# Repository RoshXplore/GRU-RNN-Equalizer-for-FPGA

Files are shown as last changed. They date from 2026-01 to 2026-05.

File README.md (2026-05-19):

# GRU(RNN)-Based Neural Network Optical Channel Equaliser on FPGA

> Note:
> This repository includes the project architecture, verification flow, FPGA deployment results, and supporting implementation files. Some internal RTL modules related to ongoing development and research work are intentionally omitted from the current public release.

Implementation of a GRU (Gated Recurrent Unit) based neural network equalizer in Verilog for digital communication systems, including both inference and on-chip training using Backpropagation Through Time (BPTT).

This project explores how recurrent neural networks can be implemented directly in hardware for adaptive channel equalization, where the communication channel characteristics vary over time and traditional DSP equalizers become less effective.

The work includes:

* Python/PyTorch model development
* Verilog RTL implementation
* FPGA deployment on Intel DE10-Lite
* On-chip GRU training using BPTT
* Gradient descent based weight updates
* RTL and FPGA verification

---

# Project Motivation

Communication channels introduce:

* noise,
* distortion,
* and inter-symbol interference (ISI).

Traditional equalizers work well for linear systems, but their complexity increases significantly for non-linear and time-varying channels.

Recurrent Neural Networks (RNNs), especially GRUs, are better suited for this problem because they maintain a hidden state that acts as memory across time steps. This allows the network to learn temporal dependencies caused by ISI.

The objective of this project was to design a trainable GRU architecture completely in Verilog that could:

* perform sequence-based equalization,
* execute inference directly on FPGA,
* and update weights on-chip using BPTT and SGD.

---

# Why GRU Instead of Standard RNN?

Standard RNNs suffer from:

* vanishing gradients,
* exploding gradients,
* unstable long-sequence training.

GRUs solve this using gating mechanisms:

* Reset Gate
* Update Gate

These gates regulate:

* how much past information should be forgotten,
* and how much should be retained.

This improves training stability and allows the model to learn temporal channel behavior more effectively.

---

# Project Evolution

The project evolved through two major stages.

---

# Phase 1 — BPSK GRU Equalizer

The first version focused on:

* understanding GRU inference in hardware,
* FPGA deployment,
* and validating basic equalization capability.

## Features

* BPSK modulation support
* GRU inference engine in Verilog
* Fixed-point arithmetic
* FPGA deployment on Intel DE10-Lite
* Python-trained weights exported into hardware

## Results

* Successfully deployed on FPGA
* Less than 1% prediction error
* Correct symbol prediction across all test cases

---

# Phase 2 — QPSK + On-Chip Training

The second version significantly expanded the architecture.

Major improvements included:

* QPSK support
* IEEE-754 floating-point arithmetic
* Serialized hardware architecture
* Backpropagation Through Time (BPTT)
* On-chip gradient calculation
* On-chip SGD weight updates
* Gradient clipping
* Hardware training controller
* Gate-state caching for temporal backpropagation

This stage focused on implementing a fully trainable recurrent neural network directly in Verilog.

---

# GRU Architecture Overview

The complete hardware architecture consists of:

```text
Input Sequence
      ↓
GRU Layer
      ↓
Linear Output Layer
      ↓
Prediction
      ↓
Loss Calculation
      ↓
BPTT Gradient Engine
      ↓
Weight Update (SGD)
      ↓
Updated Parameters
```

---

# Block Diagram

The following diagram shows the overall hardware architecture used for inference and on-chip training.

The design contains:

* GRU inference modules,
* BPTT training modules,
* gradient accumulation,
* and SGD-based weight update engines.

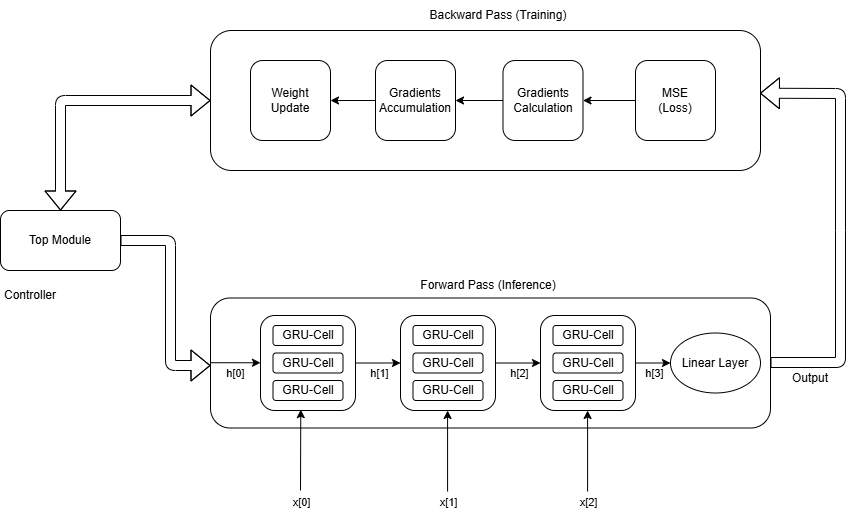
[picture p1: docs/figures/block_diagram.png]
System Architecture


**Figure:** *Top-level architecture of the GRU-based equalizer and training pipeline.*

---

# Training Flowchart

The flowchart below summarizes the complete hardware training process.

The controller:

1. initializes weights,
2. performs forward inference,
3. stores intermediate gate states,
4. computes gradients using BPTT,
5. updates weights using SGD,
6. repeats until convergence.

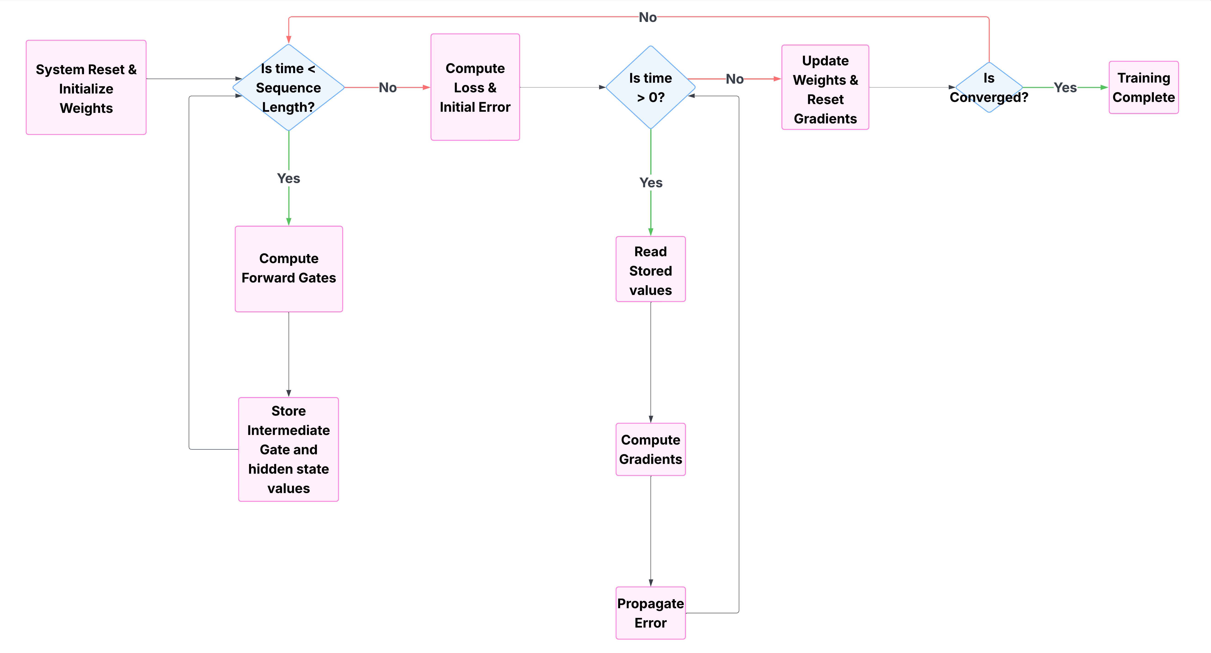
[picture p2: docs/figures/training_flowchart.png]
Training Flow


**Figure:** *Flowchart of the complete hardware training algorithm.*

---

# GRU Equations Implemented in Hardware

The following GRU equations were implemented directly in Verilog.

---

## Reset Gate

```text
rt = σ(Wrxt + Urht−1 + br)
```

Controls how much previous memory should be discarded.

---

## Update Gate

```text
zt = σ(Wzxt + Uzht−1 + bz)
```

Controls how much past information should be retained.

---

## Candidate State

```text
nt = tanh(Whxt + rt(Uhht−1) + bh)
```

Computes the new candidate memory.

---

## Final Hidden State

```text
ht = (1 − zt)nt + ztht−1
```

Combines previous memory with newly computed information.

---

# Hardware Design Philosophy

One of the main engineering challenges was FPGA resource limitation.

A fully parallel floating-point GRU implementation would consume large amounts of:

* DSP blocks,
* logic elements,
* and memory resources.

To solve this, the design uses a serialized architecture.

Instead of instantiating many FPUs in parallel:

* arithmetic units are reused sequentially,
* FSMs schedule operations,
* and intermediate gate states are cached for BPTT.

This significantly reduced hardware usage while still supporting complete training functionality.

---

# Major Verilog Modules

---

# Arithmetic Units

## Floating Point Multiplier / Adder / Subtractor

IEEE-754 single precision arithmetic modules used throughout the design.

Used for:

* matrix multiplication,
* gate computation,
* loss calculation,
* gradient computation,
* and SGD updates.

---

# Dot Product Unit (`dot_product`)

Computes vector dot products using a serialized multiply-accumulate architecture.

Instead of parallel MAC units:

* one multiplier and one adder are reused iteratively,
* controlled using FSM scheduling.

This reduced FPGA resource utilization significantly.

---

# Activation Function Modules

## `SigMoid`

Implements sigmoid activation using LUT approximation.

## `tanh`

Implements tanh activation using LUT approximation.

Instead of directly calculating exponentials in hardware:

* precomputed activation values are stored in ROM,
* floating-point inputs are mapped to LUT addresses.

This greatly reduces hardware complexity.

---

# Gradient Clipper

Implements gradient clipping to prevent exploding gradients during training.

The module:

* limits gradient magnitude,
* stabilizes training,
* and prevents numerical overflow.

---

# GRU Inference Modules

---

# Gate Calculation Unit (`gate_cal`)

Computes:

* reset gate,
* update gate,
* candidate hidden state.

Uses:

* dot product engines,
* activation modules,
* and floating-point arithmetic units.

---

# GRU Cell (`GRU_Cell_BPTT`)

Implements one GRU timestep.

The FSM sequence:

1. Reset gate computation
2. Update gate computation
3. Candidate state computation
4. Final hidden state update

Internal gate outputs are also stored for later use during BPTT.

---

# GRU Layer (`GRU_Layer_BPTT`)

Processes the complete sequence.

Responsibilities include:

* iterating through timesteps,
* maintaining hidden states,
* caching intermediate values,
* and coordinating serialized GRU-cell execution.

---

# Linear Layer (`linear_layer`)

Maps the final hidden state to:

* predicted I component,
* predicted Q component.

Used as the final output stage for QPSK prediction.

---

# Training Architecture

A major contribution of this project was implementing on-chip training directly in hardware.

Unlike inference-only accelerators, this design computes gradients and updates weights internally.

---

# BPTT Controller (`Training_Controller`)

Controls the complete training process.

## Forward Pass

* processes input sequences,
* stores intermediate states,
* computes prediction outputs.

## Backward Pass

* traverses timesteps in reverse order,
* computes gradients,
* accumulates updates,
* triggers SGD weight updates.

---

# GRU Backward Engine (`GRU_Backward`)

Implements:

* chain rule calculations,
* temporal gradient propagation,
* weight gradient calculation.

Uses stored:

* hidden states,
* reset gates,
* update gates,
* candidate states.

---

# Weight Update Engine

Implements SGD updates using:

```text
Wnew = Wold − η∇W
```

where:

* η = learning rate
* ∇W = computed gradient

---

# FPGA Platform

## Hardware

* Intel DE10-Lite FPGA

## Tools Used

* Verilog HDL
* Intel Quartus Prime
* ModelSim
* Vivado
* Python
* PyTorch
* NumPy
* Matplotlib

---

# Network Configuration

| Parameter | Value |
| --- | --- |
| Modulation | QPSK |
| Input Features  | 2 (I/Q) |
| Hidden Units | 3 |
| Output Features | 2 |
| Sequence Length | 3 |
| Precision | IEEE-754 Float32 |
| Loss Function | Mean Squared Error |

---

# Python Golden Model

Before hardware implementation, the GRU architecture was first developed and validated in Python using PyTorch.

The Python model was used to:

* verify GRU convergence behavior,
* validate BPTT equations,
* export trained weights,
* and compare RTL outputs against software references.

---

# Python Training Results

---

## QPSK Constellation Diagram

The trained Python model correctly learned the QPSK constellation mapping and accurately predicted transmitted symbols.

The clustering of predicted points around the ideal constellation locations confirms successful equalization and low prediction error.

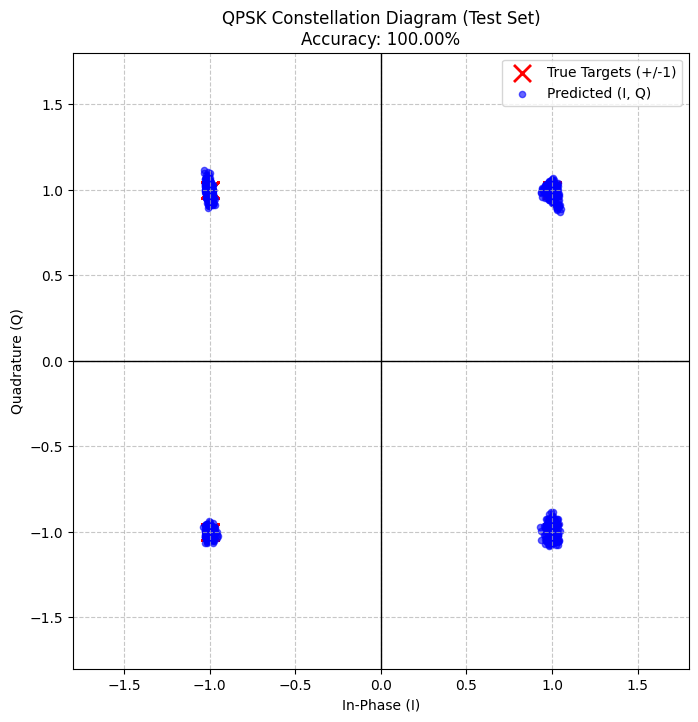
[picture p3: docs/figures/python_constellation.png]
QPSK Constellation


**Figure:** *QPSK constellation diagram generated from the trained Python model.*

---

## MSE vs Epoch

The Mean Squared Error converged rapidly during training.

Most convergence occurred within the first 25 epochs, indicating that the GRU architecture successfully learned the channel characteristics.

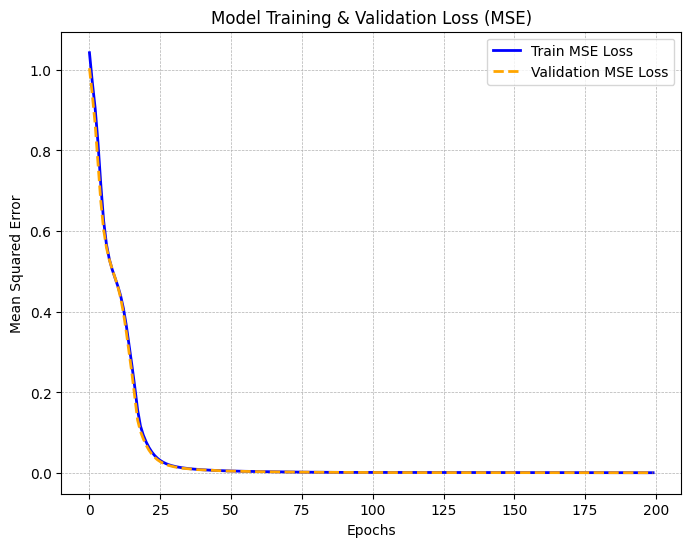
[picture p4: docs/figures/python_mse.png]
Python MSE


**Figure:** *Training and validation MSE convergence of the Python GRU model.*

---

## Weight Stability Analysis

The L2 norm of the weights was monitored during training to observe convergence behavior.

The curve stabilizes after training progresses, indicating stable parameter convergence.

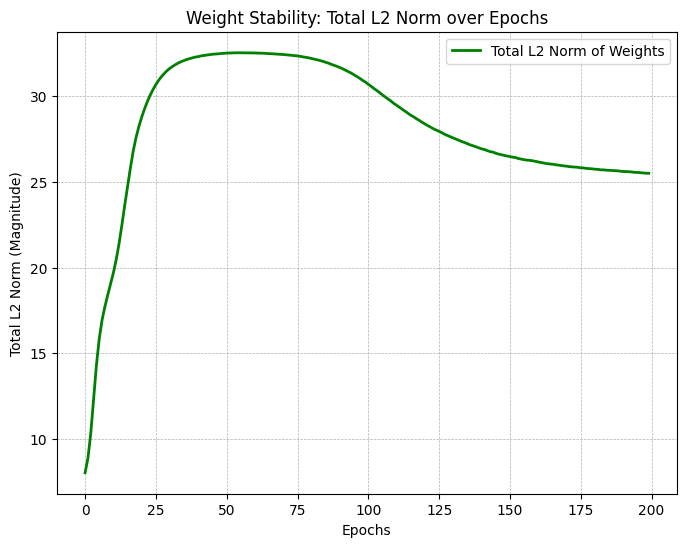
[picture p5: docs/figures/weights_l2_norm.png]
Weight Stability


**Figure:** *L2 norm of GRU weights across training epochs.*

---

# RTL Simulation Results

After validating the architecture in Python, the complete GRU inference and training pipeline was implemented in Verilog and tested using RTL simulation.

The RTL implementation reproduced the expected convergence behavior observed in software.

---

## RTL Training Convergence

The RTL simulation demonstrated successful convergence of the hardware training loop.

The Mean Squared Error reduced from:

* 0.8931
  to
* 0.0089

over 50 training epochs.

This verified:

* correctness of the BPTT equations,
* gradient propagation logic,
* and hardware SGD updates.

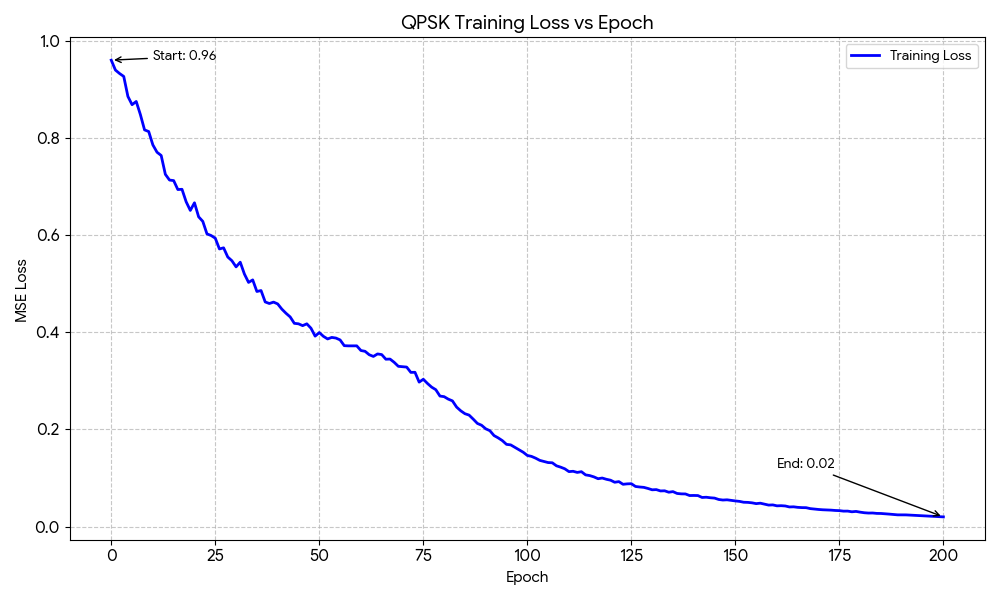
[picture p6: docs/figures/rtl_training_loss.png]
RTL Loss


**Figure:** *Training loss convergence during RTL simulation.*

---

# FPGA Hardware Validation

The design was tested on Intel DE10-Lite FPGA hardware.

Both inference and training behavior were validated using:

* Python-exported weights,
* on-chip training logic,
* and hardware-generated outputs.

---

## FPGA Constellation Output

The FPGA implementation correctly reproduced the QPSK constellation points with high accuracy.

Measured performance:

* MSE ≈ 0.001373
* Accuracy ≈ 99.86%

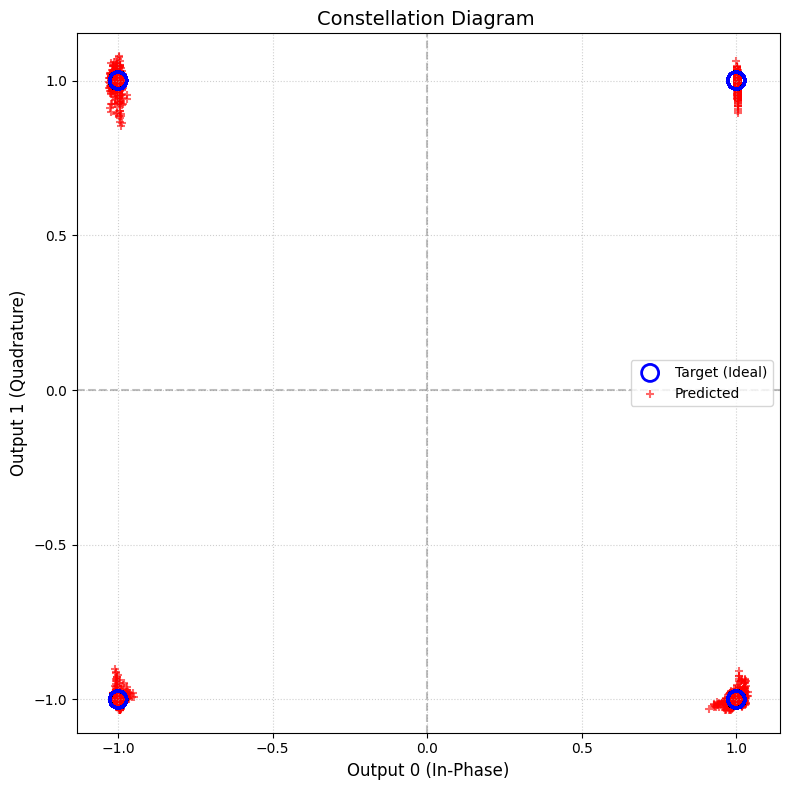
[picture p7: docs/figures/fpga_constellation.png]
FPGA Constellation


**Figure:** *Constellation diagram generated from FPGA inference outputs using Python-exported weights.*

---

## FPGA On-Chip Training Results

The FPGA implementation successfully demonstrated on-chip learning using SGD-based weight updates.

The hardware training loop reduced the loss from:

* 0.96
  to
* 0.0187

over 200 epochs.

Although oscillations are present, the overall trend confirms successful convergence of the hardware training architecture.

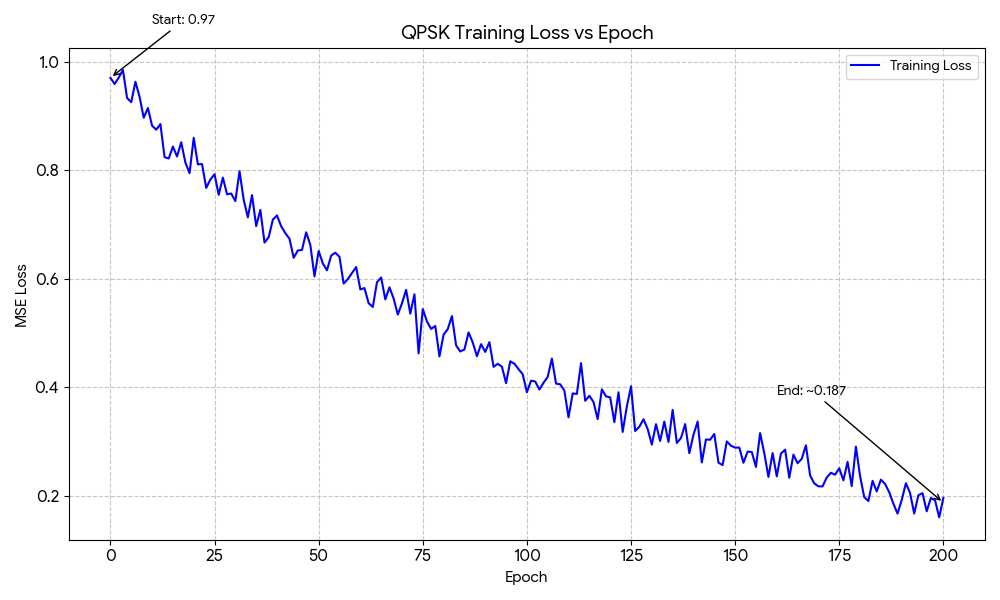
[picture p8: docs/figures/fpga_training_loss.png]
FPGA Training Loss


**Figure:** *Hardware training loss convergence on Intel DE10-Lite FPGA.*

---

# Verification Methodology

The project was verified at multiple stages.

## Python Validation

* Verified GRU convergence behavior
* Verified constellation prediction accuracy
* Verified exported weight correctness

## RTL Simulation

* Compared RTL outputs against software references
* Verified gradient convergence during training
* Verified BPTT arithmetic correctness

## FPGA Validation

* Verified inference outputs on FPGA
* Verified training convergence on hardware
* Verified QPSK constellation reconstruction

---

# Exported Weights

Weights trained in Python were exported and loaded into the Verilog architecture for inference validation.

The exported parameters included:

* Reset gate weights
* Update gate weights
* Candidate state weights
* Hidden-state matrices
* Output layer weights
* Bias vectors

This enabled direct comparison between:

* Python outputs,
* RTL simulation outputs,
* and FPGA outputs.

---

# Future Improvements

Possible future improvements include:

* Adam/RMSProp optimizer implementation
* BF16 or mixed-precision arithmetic
* Larger hidden-state architectures
* Multi-layer GRUs
* LSTM implementation
* AXI-stream interfaces
* Longer sequence support
* Improved activation approximations
* Better memory optimization

---

# References

[1] A. Bhawsar and A. Srivastava, “Multilayer perceptron equalizer using neural network accelerators,” IIT Goa, Goa, India, B.Tech. Project Report, 2025.

[2] P. J. Freire et al., “Implementing neural network-based equalizers in coherent optical transmission systems using field-programmable gate arrays,” *Journal of Lightwave Technology*, vol. 41, no. 12, pp. 3797–3812, Jun. 2023. doi:10.1109/JLT.2023.3272011

[3] F. Ortega-Zamorano, J. M. Jerez, D. U. Muñoz, R. M. Luque-Baena, and L. Franco, “Efficient implementation of the backpropagation algorithm in FPGAs and microcontrollers,” *IEEE Transactions on Neural Networks and Learning Systems*, vol. 27, no. 9, pp. 1840–1853, Sep. 2016. doi:10.1109/TNNLS.2015.2460991

[4] Y. Umuroglu et al., “FINN: A framework for fast and flexible quantized neural network inference,” *IEEE Transactions on Computers*, vol. 70, no. 4, pp. 631–644, Apr. 2021.

[5] K. Cho et al., “Learning Phrase Representations using RNN Encoder–Decoder for Statistical Machine Translation,” in *Proceedings of the Conference on Empirical Methods in Natural Language Processing (EMNLP)*, Doha, Qatar, Oct. 2014, pp. 1724–1734. doi:10.3115/v1/D14-1179

[6] S. Mandal et al., “FPGA-based online learning using approximate hardware accelerators,” in *Proceedings of the International Conference on Field-Programmable Logic and Applications (FPL)*, 2021.

---

# Author

Roshan Sharma
B.Tech, Electrical Engineering
IIT Goa

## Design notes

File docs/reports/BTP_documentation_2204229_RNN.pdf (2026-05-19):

# Documentation: RNN Channel Equalizer

By Roshan Sharma (2204229)

# Module Descriptions

A. Arithmetic and Activation
These modules constitute the fundamental mathematical processing units utilized throughout the hierarchy.
- multiplier, adder, subtractor (FP32)
- Functional Description: Implementing IEEE-754 compliant single-precision floating-point arithmetic operations.
- Application: Instantiated within higher-level modules to execute matrix-vector multiplications and gradient descent updates.
- dot_product
- Functional Description: Computes the scalar product of two input vectors
- Design Optimization: Utilizes a sequential Finite State Machine (FSM) to drive a single multiplier-accumulator pair, processing vector elements iteratively. This significantly reduces usage compared to parallel implementation.
- tanh / SigMoid
- Functional Description: Approximates non-linear activation functions essential for GRU gating logic.
- Design Optimization: Implements a Look-Up Table (LUT) architecture with 4096 entries. A custom address decoding logic inspects the IEEE exponent field to identify saturation regions, mapping only the active non-linear range of the function to physical memory.
- gradient_clipper
- Functional Description: Enforces a magnitude constraints on gradient values (e.g., = ±1.0) to mitigate the "Exploding Gradient" phenomenon prevalent in RNN training.
- Design Optimization: Performs magnitude comparison using integer-based logic on the raw floating-point bit fields, ensuring single-cycle latency without requiring floating-point comparators.
B. Inference
These modules are responsible for the input-to-output data flow, calculating the network prediction.

- gate_cal
- Functional Description: The primary Arithmetic Logic Unit (ALU) for the GRU. It computes the activation equations.
- Application: Used to calculate the Reset Gate), Update Gate, and the Candidate Hidden State.
- GRU_Cell_BPTT
- Functional Description: Orchestrates the computational sequence for a single GRU neuron.
- Application: Implements a two-phase FSM. Phase 0 computes the Reset gate; Phase 1 computes the Update gate and the final new state equation.
- GRU_Layer_BPTT
- Functional Description: Manages the computation for the complete hidden layer (comprising 3 units).
- Application: Implements serialization of the GRU_Cell. It iterates through neuron indices (0 to 2), reusing the single cell instance. Crucially, it buffers intermediate states into local cache memory, which is a prerequisite for the subsequent BPTT process.
- linear_layer
- Functional Description: The fully connected output layer mapping the Hidden State vector to the final QPSK prediction (In-Phase and Quadrature components).
C. Training
These modules implement the multivariate Chain Rule to derive gradients for weight optimization.
- mse_loss
- Functional Description: Computes the Mean Squared Error (MSE) objective function and derives the initial error gradient relative to the output.
- linear_layer_backward
- Functional Description: Propagates the error gradient from the Output Layer back to the Hidden Layer inputs.
- GRU_Backward
- Functional Description: The core calculus engine implementing BPTT.
- Application: It accepts the gradient from the subsequent timestep (t+1) and the cached forward states. It computes partial derivatives for all weight matrices (W, U, b) and derives the error gradient to be propagated to the previous timestep (t-1).

D. Control
- Training_Controller
- Functional Description: The master controller managing the temporal sequence of operations.
- Application:
- Forward Phase: Feeds input sequences to the network and triggers state snapshotting to Cache Memory.
- Backward Phase: Iterates time backwards (T to 0), retrieves cached, and drives the GRU_Backward module.
- Batch Management: signals weight updates only upon the completion of a defined BATCH_SIZE.
- GRU_top
- Functional Description: The top-level module housing the physical weight registers and the Stochastic Gradient Descent (SGD) engine.
- Application:
- Initialization: Utilizes a Linear Feedback Shift Register (LFSR) to initialize weights with pseudo-random floating-point values.
- Update Engine: Employs a multiplexing scheme to iterate through all parameter sets, updating them using a shared arithmetic pipeline via the SGD rule: W_new = W_old – lr*gradient
- weight_updater_single / gradient_accumulator_single
- Functional Description: Wrappers for arithmetic cores that enforce a handshake protocol, preventing race conditions during register updates.
E. FPGA Interface
- fpga_top_module
- Functional Description: The physical abstraction layer for the DE10-Lite FPGA board.
- Application: Interacts with on-board peripherals including the ROM (Dataset), PLL (Clock Generation), and I/O interfaces (Switches/LEDs).

# Parameters

### 1. BATCH_SIZE

- Description: The number of samples accumulated before a weight update occurs.
- Modification:
- Smaller Batch: Faster updates, more noisy convergence (stochastic).
- Larger Batch: More stable gradients, slower updates.
2. SAMPLES_PER_EPOCH (Default: 3500).
- Description: Defines the cycle length for logging and epoch counting.
- Modification: Match this to the size of the dataset stored in the ROM to ensure accurate epoch tracking.
3. CLIP_VAL (Default: 1.0)
- Description: The threshold for the gradient_clipper module.
- Modification: Adjusting this hex value changes the gradient clamping limit, which acts as a hyperparameter for training stability.
4. INPUT_FEATURES (Default: 2)
- Description: Defines the dimensionality of the input vector.
- Modification:
- Set to 1 for Real-valued signals (e.g., BPSK).
- Set to 2 for Complex-valued signals (e.g., QPSK, I/Q data).

### 5. GRU_UNITS (Default: 3)

- Description: Defines the size of the hidden state vector (number of neurons).
- Modification: Increasing this value improves the model's capacity to learn complex non-linear distortions but increases FPGA resource usage linearly.
6. OUTPUT_SIZE (Default: 2)
- Description: Defines the size of the final prediction vector.
- Modification:
- Set to 1 for binary classification.
- Set to 2 for I/Q symbol prediction.
7. SEQUENCE_LENGTH (Default: 3)
- Description: Defines the BPTT unrolling depth (time steps).
- Modification: Increase this parameter to capture longer-term Inter-Symbol Interference (ISI) in highly dispersive channels. Note that BRAM usage for caching scales linearly with this parameter.

# Exported weights from Python model (for inference)

Wr (Reset Input)
Wr_flat[0*32 +: 32] = 32'hbdbb8b27; Wr_flat[1*32 +: 32] = 32'h3ee5fecb; Wr_flat[2*32 +: 32] = 32'h3e8b0b17; Wr_flat[3*32 +: 32] = 32'hbe0b83a1; Wr_flat[4*32 +: 32] = 32'hbf465abc; Wr_flat[5*32 +: 32] = 32'hbf89c6a3;

Ur (Reset hidden)
Ur_flat[0*32 +: 32] = 32'hbe8894dd; Ur_flat[1*32 +: 32] = 32'hbf063418; Ur_flat[2*32 +: 32] = 32'h3f4b5add; Ur_flat[3*32 +: 32] = 32'hbf2dbf62; Ur_flat[4*32 +: 32] = 32'h3e8d4890; Ur_flat[5*32 +: 32] = 32'h3fb7dd50; Ur_flat[6*32 +: 32] = 32'hbdf13aa2; Ur_flat[7*32 +: 32] = 32'hbf1efec5; Ur_flat[8*32 +: 32] = 32'hbedcae16;

br (Reset Bias)
br_flat[0*32 +: 32] = 32'h3fbee325; br_flat[1*32 +: 32] = 32'h3f1921fa; br_flat[2*32 +: 32] = 32'h3f38ef97;

Wz (Update Input)
Wz_flat[0*32 +: 32] = 32'hbf3ac95e; Wz_flat[1*32 +: 32] = 32'h3f0648a8; Wz_flat[2*32 +: 32] = 32'h3d142a72; Wz_flat[3*32 +: 32] = 32'hbd5348fe;

Wz_flat[4*32 +: 32] = 32'h3eb35010; Wz_flat[5*32 +: 32] = 32'h3e87ccf2;

Uz (Update hidden)
Uz_flat[0*32 +: 32] = 32'h3efdea76; Uz_flat[1*32 +: 32] = 32'h3ec47954; Uz_flat[2*32 +: 32] = 32'hbe6de2af; Uz_flat[3*32 +: 32] = 32'h3f297d18; Uz_flat[4*32 +: 32] = 32'h3e201356; Uz_flat[5*32 +: 32] = 32'hbf98501a; Uz_flat[6*32 +: 32] = 32'h3f7c3779; Uz_flat[7*32 +: 32] = 32'hbfb94f40; Uz_flat[8*32 +: 32] = 32'hc07752e1;

bz (Update Bias)
bz_flat[0*32 +: 32] = 32'hbfc6783d; bz_flat[1*32 +: 32] = 32'hbfc72bf9; bz_flat[2*32 +: 32] = 32'hbfca04b4;

--- Wh (New Input)
Wh_flat[0*32 +: 32] = 32'h3df5a05f; Wh_flat[1*32 +: 32] = 32'hbf3c972b; Wh_flat[2*32 +: 32] = 32'h3ddc4e13; Wh_flat[3*32 +: 32] = 32'h3c4c9b12; Wh_flat[4*32 +: 32] = 32'h3ee68962; Wh_flat[5*32 +: 32] = 32'h3f286cc9;

--- Uh (New hidden)
Uh_flat[0*32 +: 32] = 32'h40297973; Uh_flat[1*32 +: 32] = 32'h3f87460f; Uh_flat[2*32 +: 32] = 32'hbfbc5cac;

Uh_flat[3*32 +: 32] = 32'hc05439c3; Uh_flat[4*32 +: 32] = 32'h3fac427c; Uh_flat[5*32 +: 32] = 32'h3f743033; Uh_flat[6*32 +: 32] = 32'h3f7ed536; Uh_flat[7*32 +: 32] = 32'hc05362b6; Uh_flat[8*32 +: 32] = 32'h406880e2;

bh (New Bias)
bh_flat[0*32 +: 32] = 32'hbe46cf47; bh_flat[1*32 +: 32] = 32'hbf45e120; bh_flat[2*32 +: 32] = 32'h3ef4754a;

FC Weights (linear layer)
fc_weights_flat[0*32 +: 32] = 32'h3c5c3f21; fc_weights_flat[1*32 +: 32] = 32'h3f87ef7e; fc_weights_flat[2*32 +: 32] = 32'h3d2b8d7a; fc_weights_flat[3*32 +: 32] = 32'hbceb175f; fc_weights_flat[4*32 +: 32] = 32'hbcfacfa5; fc_weights_flat[5*32 +: 32] = 32'hbf95cfd6;

FC Bias
fc_bias_flat[0*32 +: 32] = 32'hbb1dc645; fc_bias_flat[1*32 +: 32] = 32'h3dfe837d;

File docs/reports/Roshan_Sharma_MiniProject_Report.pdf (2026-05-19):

# Design of an On-Chip Trainable GRU-based

# Channel Equalizer On FPGA

## Roshan Sharma (2204229), Final Year B.Tech Student

Project Superviser: Dr. Nandakumar Nambath

Abstract—This project presents a Gated Recurrent Unit (GRU) based hardware accelerator with on-chip training using Back Propagation Through Time (BPTT) for adaptive channel equalization in communication systems, particularly suited for scenarios where the channel characteristics vary over time. It utilizes IEEE 754 single precision floating point arithmetic for high precision inference and faster gradient descent. Hardware was serialized to offset the resource constraint bottleneck. The design was verified through RTL simulation and implementation in DE-10 Lite, and successfully performed inference (MSE < 0.2%) in hardware and simulation results and the error successfully

converged when training on FPGA in a small sample.
Index Terms—FPGA, Verilog, GRU, On-Chip Training, BPTT, FPU, Channel Equalization, RNN, Hardware Accelerator, QPSK.

## I. INTRODUCTION

Neural networks have become widely popular due to their

simpler architecture and adaptive nature. One such

application is in communication systems where, due to rise in

data traffic, has shifted to higher order modulation techniques

and symbol rates [2]. However, it introduces severe non-linear

impairments which traditional Digital Signal Processing (DSP)

techniques require higher complexity to compensate for.

Traditionally used neural network-based equalizers like Con-

volutional Neural Networks | (CNN) or | Multilayer | Percep-

trons (MLP) [1] are feed-forward architectures and cannot

effectively compensate for the Inter-Symbol Interference (ISI)

which creates temporal dependencies between the inputs as

they are memoryless.

To mitigate this issue, Recurrent Neural Networks (RNN),

specifically Gated Recurrent Units (GRU) can be used as their

internal hidden | state acts as a memory, allowing them | to
implicitly model the ISI.

Current hardware implementations of NN-based equalizers

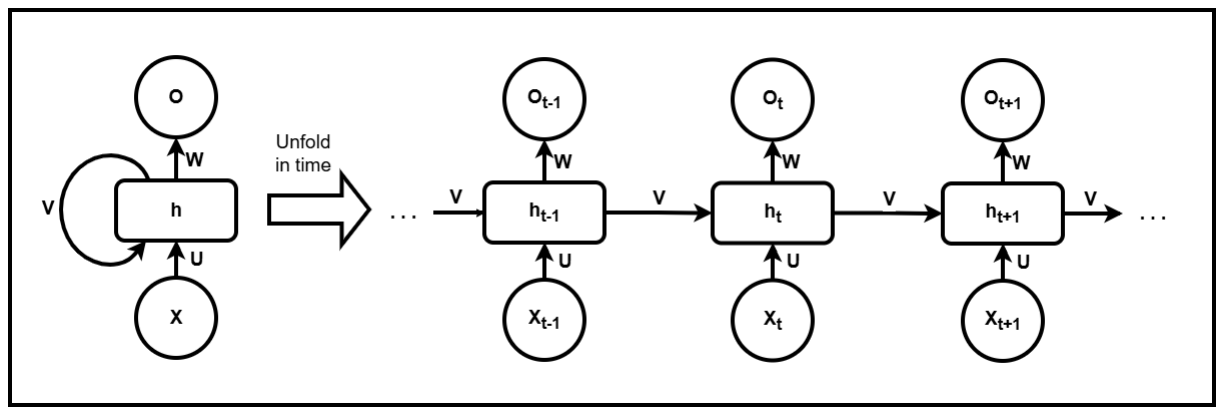
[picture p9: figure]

typically use | offline | training, where | the | model is | trained

on a computer using a static dataset and then the weights

are exported onto the chip. This approach, although simpler

and resource-efficient, cannot accommodate for the changing

channel conditions [6].

This project proposes a modular and training capable design

for adaptive channel conditions. By implementing Back Propa-

gation Through Time (BPTT) algorithm in Verilog, the FPGA

can calculate error gradients and perform gradient descent to

update the weights.

## II. OBJECTIVES

# A. Selection of RNN type

As vanilla vanilla recurrent neural networks (RNN) suffers

from exploding and vanishing gradient problem, advanced

models such as Long-Short Term Memory (LSTM) and Gated

Recurrent Unit (GRU) overcomes these issues through gating

mechanisms, by selectively forgetting or remembering infor-

mation, thereby these gates create direct paths in the network.

# B. Design of Python Model

The | next goal was | to | design | the | whole | architecture | in

Python using the PyTorch library and simulating it to observe

if the weights are settling and mean-squared error (MSE)

is converging and then exporting the weights for hardware

simulation. This also involved debugging where the hardware

modules are failing while comparing with the Python model.

# C. Design of Verilog Inference Modules

This stage involved building the forward pass (inference)

modules in Verilog and testing it on RTL(Register Transfer

Level) simulation and FPGA using the exported weights from

Python. This stage also involved choosing the type of imple-

mentation of activation functions, i.e., the Tanh and Sigmoid

functions | which could be | implemented in | hardware | using

Look-up tables (LUTs), Piecewise linear approximation (PWL)

or Taylor series expansion [2].

# D. Design of Training Modules

The | final stage | involved building the | backpropagation

through time (BPTT) modules and modifying the inference

modules to store intermediate gate atesting it on Behavioral

simulation and FPGA. This required learning to derive the

necessary equations to be implemented and how to optimize

it for hardware implementation.

### Fig. 1. Basic RNN Working

## III. THEORY

The proposed design forms on basis of the following theory:

# A. RNN Architecture

A standard RNN processes sequential data by maintaining

a “hidden state” vector (ℎt) that acts as a short-term memory

[2]. At every time step t, this state is updated by combining the

current input (xt) and the previous state (ℎt−1) using a tanh

activation function:

ℎt = tanh (Wzℎxt + Wℎℎℎt−1 + b) | (1)

And the output is given by:

o = Wf c ℎt + b f c | (2)

Where W and b refer to the corresponding weights and biases,

respectively.

As depicted in Fig. 1, the basic cell unfolds in time for multiple

numbers of times, which is equal to the input sequence length.

This recurrent loop of hidden state allows the network to pass

information forward through time, enabling it to model temporal

dependencies.

But training an RNN requires Backpropagation Through Time

(BPTT), where error gradients are propagated backward from

the last time step to the first [3]. This mathematically involves

repeated multiplication of the recurrent weight matrix (Wℎℎ).

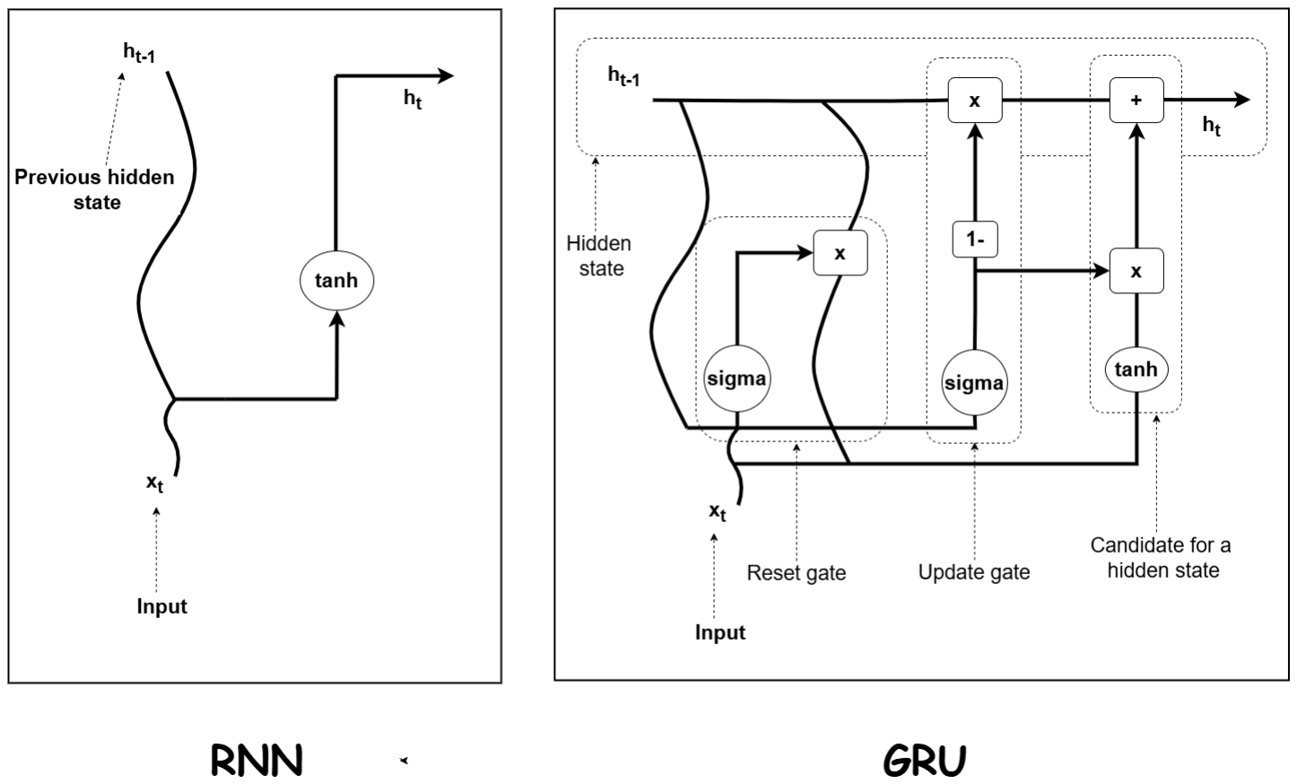
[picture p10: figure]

Fig. 2. Basic RNN vs GRU structure

# Vanishing Gradient: If the weights are small (< 1), the

gradients shrink exponentially as they travel back. The network

effectively “stops learning” from early inputs, making it unable

to capture long-term dependencies.

Exploding Gradient: If weights are large (> 1), gradients

grow exponentially, causing numerical overflow (NaNs) and

destabilizing the hardware training loop.

To resolve this, this project implements the Gated Recurrent

Unit (GRU) [5] as shown in Fig. 2. Unlike a simple RNN, the

GRU introduces explicit gating mechanisms, the Update Gate

(zt) and Reset Gate (rt), to regulate information flow.

The equations implemented in the Verilog hardware are:

1) Reset gate (rt): Decides how much past information to

discard.

rt = σ (Wr xt + Ur ℎt−1 + br ) | (3)
2) Update gate (zt): Decides how much past information to

keep.

zt = σ (Wz xt + Uzℎt−1 + bz ) | (4)
3) Candidate state (nt): Computes new memory content.
nt = tanh (Wℎxt + rt ⊙ (Uℎℎt−1) + bℎ) | (5)
4) Final hidden state (ℎt): Mixing old and new memory.
ℎt = (1 − zt) ⊙ nt + zt ⊙ ℎt−1 | (6)

The final equation creates an additive path for gradients.

If zt ≈ 1, the previous state is copied directly to the current

state. This allows gradients to flow backward unchanged over

many time steps, effectively solving the vanishing and exploding

gradient problem and enabling the hardware to learn long

sequences stably.

The output equation remains the same:

o = Wf c ℎt + b f c | (7)

# B. Backpropagation Through Time (BPTT)

Training a Gated Recurrent Unit (GRU) differs from standard

feedforward networks because the parameters (W, U, b) are

shared across all time steps. To compute gradients, the network

is mathematically “unfolded” through time, creating a deep feed-

forward network with T layers (where T is the sequence length).

The training process, known as Backpropagation Through Time

(BPTT), involves propagating error signals from the last time

(t = T) step back to the first (t = 1) [3].

The objective of training is to minimize the Loss (L), which is

taken to be the mean squared error (MSE) between the target and

the predicted values as shown in Equation 8. BPTT calculates

how much each weight contributed to this error by computing

the gradient of the loss with respect to the weights (ΔW). These

gradients are then subtracted from the previous weights’ value

with a scaled parameter known as the learning rate (η). The

inference is again run with the updated weights and then the

loss is again calculated. This process is done again and again and

eventually the weights settle and therefore the model is trained.

This process is called Stochastic Gradient Descent (SGD).

## L(Loss) =

1

2

## ∥yD − yP ∥

2
(8)

Where,

yD =

yI,D

## yQ,D

(9)

(Refers to the target QPSK symbol comprising of In-phase

and Quadrature components.)

and

yP =

yI,P

## yQ,P

(10)

(Refers to the predicted QPSK symbol comprising of In-phase

and Quadrature components.)

The gradient of Loss with respect to predicted output,

∂L

∂yP

= (yD − yP) | (11)

Output layer gradients:

∂L

## ∂W( f c)

=

∂L

∂yP

ℎ

T
T

(12)

∂L

∂ℎT

= WT
( f c)
∂L

∂yP

(13)

Gate gradients (per timestep):

- Candidate:

∂L

∂nt

=

∂L

∂ℎt

⊙ (1 − zt) | (14)

∂L

∂at

n

=

∂L

∂nt

⊙ (1 − n

2

t

) | (15)
- Update gate:

∂L

∂zt

=

∂L

∂ℎt

⊙ (ℎ(t−1) − nt) | (16)

∂L

∂at
z

=

∂L

∂zt

⊙ zt(1 − zt) | (17)
- Reset gate:

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
⊙ ℎ(t−1) | (18)

∂L

∂at

r

=

∂L

∂rt

⊙ rt(1 − rt) | (19)

Weight gradients:

- Candidate:

∂L

∂W(n)

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
(20)

∂L

∂U(n)

=

∑︁
∂L

∂at

n

(rt ⊙ ℎ(t−1))

T
(21)

∂L

∂bn

=

∑︁
∂L

∂at

n

(22)
- Update gate:

∂L

∂W(z)

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
(23)

∂L

∂U(z)

=

∑︁
∂L

∂at
z
ℎ

T
(t−1)

(24)

∂L

∂bz

=

∑︁
∂L

∂at
z
(25)
- Reset gate:

∂L

∂W(r )

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
(26)

∂L

∂U(r )

=

∑︁
∂L

∂at

r

ℎ

T
(t−1)

(27)

∂L

∂br

=

∑︁
∂L

∂at

r

(28)

# Gradient Propagation through timesteps:

∂L

∂ℎ(t−1)

=

∂L

∂ℎt

⊙ zt +
U

T
(n)
∂L

∂at

n

⊙ rt

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
(r )
∂L

∂at

r

(29)

# Weight update:

## θ = θ − η

∂L

∂θ
(30)

where η is the learning rate, θ represents any weight parameter

and the summation for weight gradients is from t = 1 to t = T.

Also, a

t

r

, a

t
z

and a

t

n

are given by:

a

t
r = W(r )xt + U(r ) ℎ(t−1) + br | (31)

a

t
z = W(z)xt + U(z) ℎ(t−1) + bz | (32)

a

t
n = W(n)xt + U(n) (rt ⊙ ℎ(t−1)) + bn | (33)

# C. Activation Functions

Activation functions are integral part of neural networks. They

help the network learn complex non-linearities by transforming

the | linear | sum | of inputs | into | non-linear | output. | Without

activations functions, the effective structure of the network

would become just a linear transformation of inputs, which

would not learn any complex patterns present in the input.

In GRUs, two activation functions are used, Sigmoid and

Tanh. Sigmoid is used to generate the reset and update gates,

whereas tanh is used to generate the Candidate state as shown

in Equations 3, 4 and 5.

Tanh is bounded between -1 to 1 whereas Sigmoid is bounded

between 0 to 1 as shown in Fig. 3.

σ(x) =

1

1 + e

−x

(34)

tanh(x) =

e

x − e

−x

e

x + e

−x

(35)

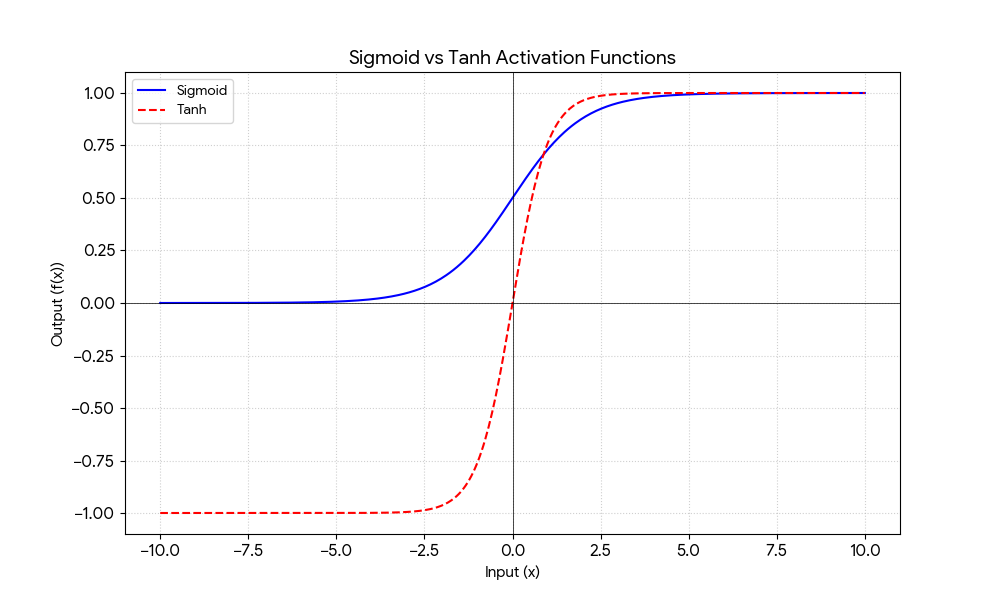
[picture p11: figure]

Fig. 3. Sigmoid and tanh activation functions used in the GRU architecture.

## IV. METHODOLOGY

# A. Model Configuration and Specifications

Before mapping the algorithm to hardware, the specific

hyperparameters of the GRU network were defined to target

the channel equalization task. To validate the hardware design,

a “Golden Model” was first developed in Python (using PyTorch

library) to generate weights.

# - Input Representation: The system is designed to process

complex-valued signals common in digital communica-

tions (QPSK). The input vector xt consists of two features

representing the In-Phase (I) and Quadrature (Q) compo-

nents of the received symbol.The bits are represented as

(I,Q) symbol format, where bits 00 are represented by (1,1),

bits 01 by (-1,1), bits 10 by (-1,-1) and bits 11 by (1,-1).

- Network Topology: The | core | GRU layer | consists | of
configurable hidden units (default parameter Nhidden | = 3)

to capture the channel memory. A linear layer maps the

final hidden state to the estimated symbol.

# - Optimization Strategy:

– Python Golden Model: Utilizes the Adam optimizer,

which uses variable learning rate for rapid convergence

during software simulation benchmarks.

– FPGA Hardware: While adaptive optimizers like

Adam improve convergence speed, they require com-

plex hardware logic for calculating running averages

and square roots. To minimize resource utilization on

the FPGA, a fixed learning rate (η) was chosen.

Before implementing the architecture in Verilog, the network

hyperparameters were frozen to balance learning capability with

FPGA resource constraints. The system parameters utilized for

the experimental validation are summarized in Table I.QPSK

was chosen as it provides twice the number of bits per symbol

than BPSK, widely used in communication systems and provides

complex representation of signals.The hidden size of three was

chosen as to be sufficient for learning the non-linearities but

also be computationally light for on-chip training. A sequence

of three was chosen to reduce the number of unfolded GRU steps, to lower the hardware memory but still be able to learn

the temporal dependencies.

### TABLE I

### HYPERPARAMETERS

Parameter | Value / Description
Modulation | QPSK (Quadrature Phase Shift Keying)
Input Features | 2 (In-Phase (I) and Quadrature (Q))
Hidden Units | 3 (Configurable)
Output | 2 (In-Phase (I) and Quadrature (Q))
Sequence Length | 3
Precision | IEEE 754 Single Precision (32-bit)
Loss Function | Mean Squared Error (MSE)

# B. Hardware Inference Implementation

To manage the complexity of the GRU-BPTT algorithm and

make it modular, the hardware is designed using a hierarchical

approach. The system is built from fundamental arithmetic

units (FPU) up to the top-level training controller and inference

module.

# 1) Dot Product Unit (dot product) The fundamental

operation in any neural network is the weighted sum
(

Í
wixi). This module implements a serialized vector-

vector multiplication. It iterates through the input vec-

tor elements, utilizing the shared single floating-point

multiplier and adder to compute the sum-of-products.

By serializing this | operation, we | avoid instantiating

large parallel adders, significantly saving FPGA Logic

Elements (LEs).

# 2) Activation Function Units (SigMoid, tanh) These mod-

ules provide the non-linear capabilities of the network.

Since calculating exponentials (e

−x
) is costly in hardware,

these units utilize Look-Up Tables (LUTs). The 32-bit

floating-point input is used to address a ROM containing

pre-computed values.

# 3) Gate Calculation Unit (gate cal) This module abstracts

the | math for | a | single | GRU gate. | It instantiates | two
dot | product units to compute the input contribution (Wx)

and the hidden state contribution (Uℎ) in parallel. It then

adds the bias and passes the result through the appropriate

activation function unit (Sigmoid or Tanh) based on a flag.

# 4) GRU Cell (GRU Cell) This module implements the

logic for a single time step. It operates as a sequencer that

triggers the gate cal unit three times in sequence:

- Step 1: Compute Reset gate (rt).
- Step 2: Compute Update gate (zt).
- Step 3: Compute Candidate state (nt).

Final Hidden State: It performs the linear computation

to produce the new hidden state. Crucially, this module

exposes all internal gate values (rt
, zt

, nt) to the top level

for storing.

# 5) GRU Layer (GRU Layer BPTT) This module man-

ages the temporal sequence. It contains the “State Regis-

ter” that stores (ℎt−1). It accepts the full input sequence

array and iteratively feeds one time-step at a time into the
GRU Cell.

# 6) Linear Output Layer (linear layer) After the GRU

Layer | processes | the | full sequence, the | final hidden

state (ℎt) is passed to this module. It performs output

computation to generate the final prediction (the estimated

QPSK symbol).

# C. Hardware Training Implementation

The BPTT Training Controller, a complex Finite State Ma-

chine (FSM) that manages the complete forward and backward

passes, for training the neural network.

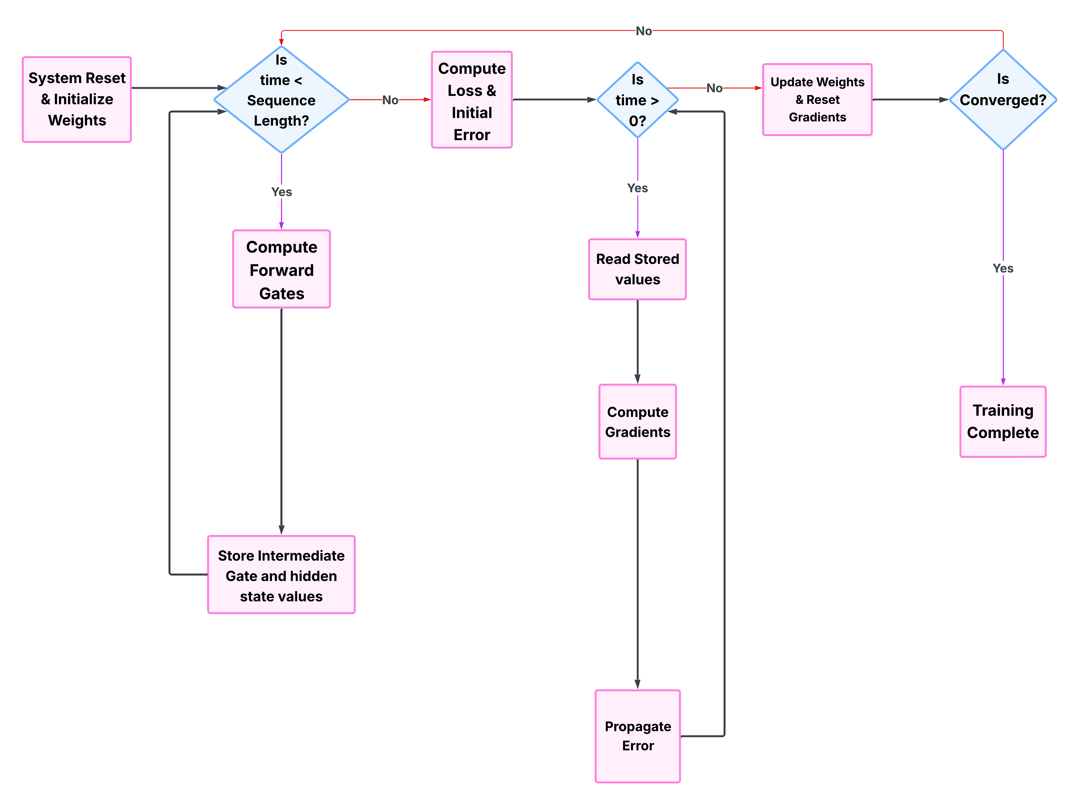
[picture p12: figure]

# 1) Inference Phase Management: The controller begins

in the inference start state. It triggers the GRU Layer to

process the input sequence. It monitors the “Done” signals

and ensures that the variables required for gradients is

correctly populated with the data of every gate activation.

# 2) Backward Propagation Units: Once the error is calcu-

lated (Loss), the controller switches to the training start

state and activates the training-specific modules:

# - Backward Cell (GRU Timestep Backward):

This module implements the chain rule equations

derived in the Theory section. It reads the rt
, zt

, nt

values from the stored registers (in reverse order, from

T down to 1) and computes the error gradients with

respect to the weights.

# - Weight Updater (weight updater): Using the gra-

dients | calculated above, this | module | applies | the

Gradient Descent (GD) weight update. It utilizes the

shared floating-point subtractor to modify the weight

registers in-place.

## V. BLOCK DIAGRAM

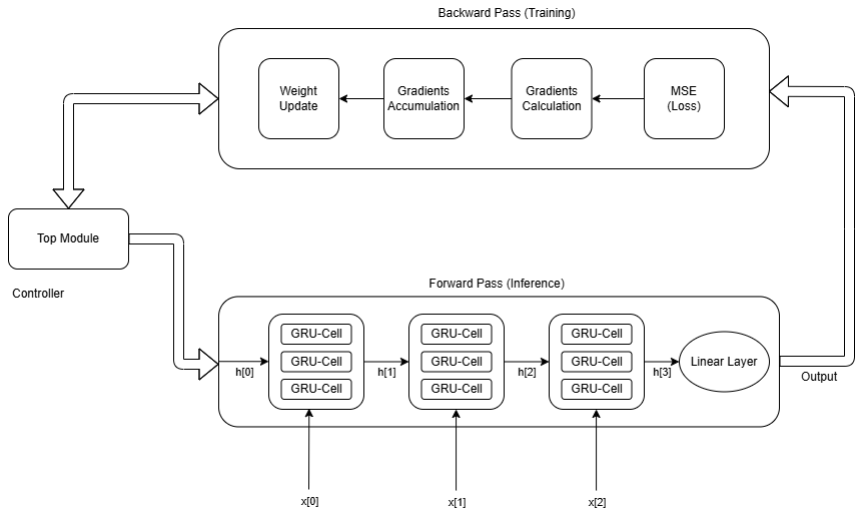
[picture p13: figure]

Fig. 4. Block diagram of Verilog modules.

The block diagram shown in Fig. 4 illustrates the overall

architecture which was used to implement both the inference

and training modules, which focused on scalability and clarity, to

correct debugging and support different modulation techniques,

with only minor changes. The top module stores all the weights

and biases and has a switch for inference and training modes.

The GRU Cell is the core of the design, calculating all the

gates and the final hidden state for each timestep.“Increasing the number of hidden units instantiates additional GRU Cells in par-

allel without increasing the overall latency. Once GRU Cells

calculates the whole sequence, the output layer calculates the

predicted symbol.

The BPTT modules calculate the loss, and the gradients and

finally update the weights. The top module supervises the whole

system.

## VI. FLOW CHART

Fig. 5. Flowchart of the whole training algorithm.

The flowchart shown in Fig. 5, outlines the whole training

algorithm. Firstly, the weights and biases are initialised, they

can be random weights as to break symmetry at the start for

faster convergence. Then the system enters the forward pass,

where GRU Cells compute the gates and hidden states and they

are also stored for calculating the gradients. The output layer

produces the predicted output and then the loss is calculated,

if the loss is not converged, the gradients are calculated and

the accumulated across total timesteps. Finally the weights are

updated and then the loop continues until the loss is converged,

or until a fixed number of epochs is reached.

## VII. MATERIALS AND SOFTWARES USED

The hardware implementation and verification were con-

ducted using the following platform specifications:

# - FPGA Development Board: Terasic DE-10 Lite - Development Environment: Intel Quartus Prime Lite

## Edition 20.1, Xilinx Vivado 2020.2

## - Simulation Tool: ModelSim, Xilinx Vivado 2020.2

# - Synthesis Language: Verilog HDL

## VIII. RESULTS AND DISCUSSION

As observed in the Fig. 7, the MSE converged around 25

epochs and the weights converged around 175 epochs in Python

as seen from Fig. 8 from weights L2 norm, which calculated

mean squared values of all weights. The inference was run on the

Python trained weights and it shows very good accuracy (MSE ¡

0.001%) and correctly predicted all transmitted constellations as

seen in Fig. 6. This proves that the model architecture is correct.

The RTL simulation showed decreasing trend in MSE for 5

samples in Fig. 9, decreasing from mse of 0.8931 to 0.0089 in 50

epochs, proving that all the modules are mathematically correct

and working as expected.

The convergence can be made faster by implementing opti-

mizers such as Adam, which keeps track of the first moment

(moving average of the gradients) and the second moment

(moving average of the squared gradients) of the gradients

and adaptively changes the learning rate. This would again

pose a hardware resource constraint but can be used if faster

convergence is a priority and to reduce the oscillations and

stuck gradients problem for large dataset.

The inference ran on DE 10 Lite board from Python exported

weights which showed mse of 0.001373 (99.86% accuracy) and

correctly predicted all the QPSK symbols as shown in Fig. 10,

validating the correctness of the implemented architecture.

The MSE vs epoch as shown in Fig. 11 for learning rate =

0.001 and 10 sample size, shows the loss decreasing from 0.96

to 0.0187 in 200 epochs. The noise in the error plot is due to the

LUT’s precision and the non-adaptive learning rate. To improve

the convergence, adaptive learning rate optimisers need to be

employed to reduce oscillations and overshoot in convergence.


Fig. 6. QPSK Constellation diagram from the trained Python

Model.


Fig. 7. MSE Vs epoch from the Python Model.


Fig. 8. Weights L2 norm Vs epoch from the Python Model.

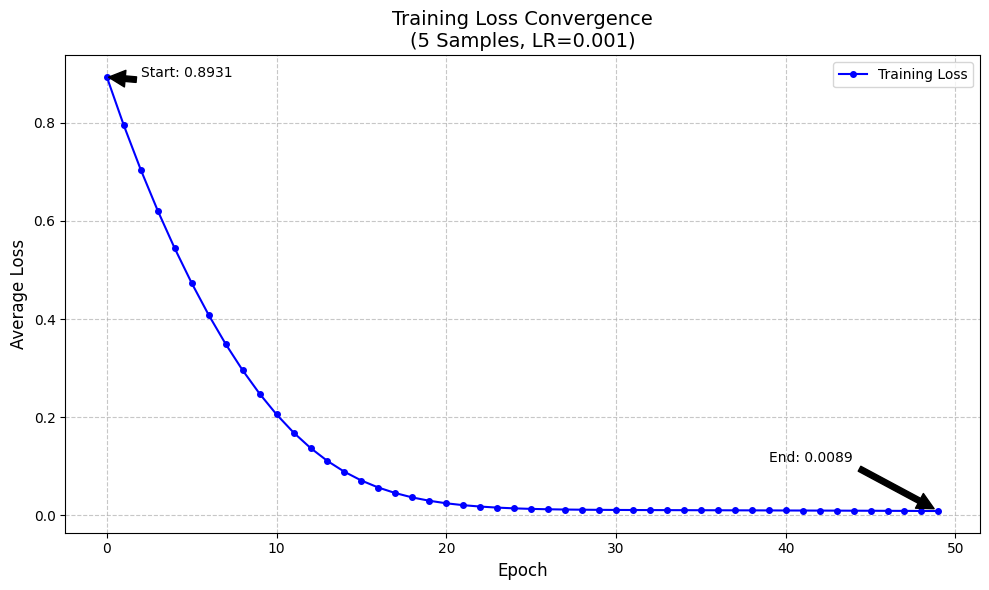
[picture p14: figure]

Fig. 9. MSE vs epoch from RTL Simulation.

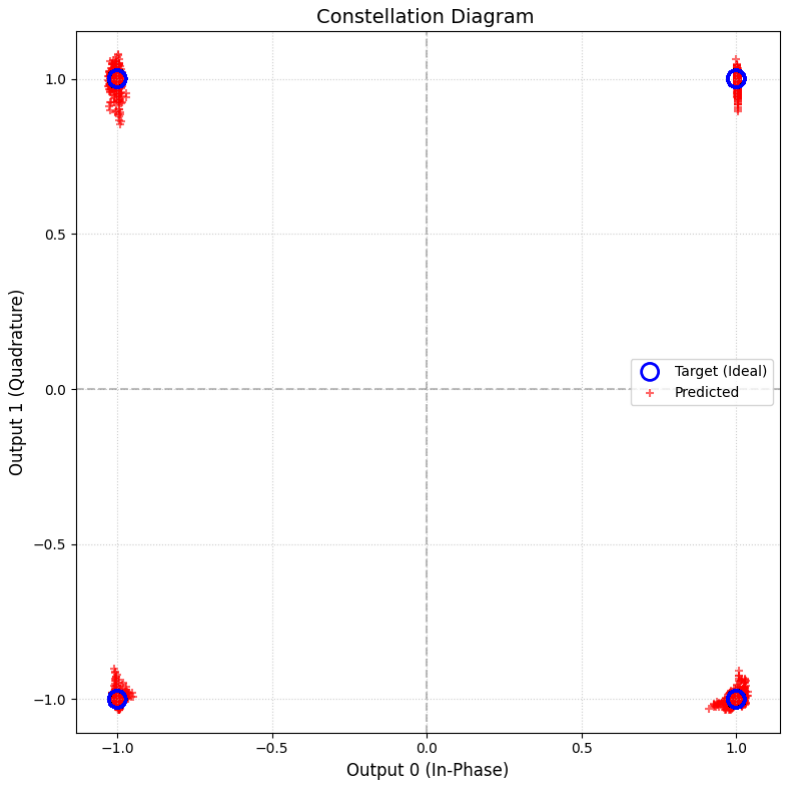
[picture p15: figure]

Fig. 10. Constellation Diagram for Python Exported weights

on DE 10 Lite.


Fig. 11. MSE vs epoch plot for 10 samples and lr= 0.001 on DE-10 Lite.

## IX. CONCLUSION

This project successfully implemented a hardware accelerator

for on-chip training of gated recurrent units (GRU), addressing

the limitation of traditional ”inference-only” FPGA designs. By

translating the complex Backpropagation Through Time (BPTT)

algorithm into a synthesizable Verilog architecture, the design

enables the equalizer to calculate gradients and update weights

dynamically without externally importing the weights.

## X. FUTURE WORKS

To further enhance the performance and applicability of this

on-chip trainer, the following improvements are proposed:

# 1) Adaptive Optimizers: Implementing Adam or RMSProp

in hardware to accelerate convergence speed for fast

changing channels.

# 2) Precision Optimization: Migrating from 32-bit Single

Precision to emerging technology like Brain Float 16

(BF16) to reduce memory usage and logic footprint

without sacrificing training stability [4].

These are just some of the optimizations, which can improve

the model and make it more efficient ad help the training

have | smoother | and faster | convergence. | There | can | also | be

architectural changes proposed like going for LSTMs albeit with

more complex architecture but captures long-range temporal

dependencies.

## ACKNOWLEDGMENT

I would like to express my sincere gratitude to my project su-

pervisor, Dr. Nandakumar Nambath, for his invaluable guidance,

continuous encouragement, and technical insights throughout

the duration of this project.

I am also deeply grateful to Mr. Akshay Gaonkar (PhD

Scholar) for his mentorship and assistance with the FPGA

implementation and verification process.

Finally, I thank the School of Electrical Sciences, IIT Goa,

for providing the necessary laboratory infrastructure and FPGA

development resources and necessary softwares required to

complete this project successfully.

References

[1] A. Bhawsar and A. Srivastava, “Multilayer perceptron equalizer using

neural network accelerators,” IIT Goa, Goa, India, B.Tech. Project Rep.,
2025.
[2] P. J. Freire et al., “Implementing neural network-based equalizers in

a coherent optical transmission system using field-programmable gate
arrays,” J. Lightw. Technol., vol. 41, no. 12, pp. 3797–3812, Jun. 2023, doi: 10.1109/JLT.2023.3272011.
[3] F. | Ortega-Zamorano, J. | M. | Jerez, D. | U. | Munoz, R. | M. | Luque- ˜

Baena, and L. Franco, “Efficient implementation of the backpropaga-

tion algorithm in FPGAs and microcontrollers,” IEEE Trans. Neural

### Netw. Learn. Syst., vol. 27, no. 9, pp. 1840–1853, Sep. 2016, doi:

10.1109/TNNLS.2015.2460991.

[4] Y. Umuroglu et al., “FINN: A framework for fast and flexible quantized

neural network inference,” IEEE Trans. Comput., vol. 70, no. 4, pp. 631–
644, Apr. 2021.
[5] K. Cho et al., “Learning Phrase Representations using RNN Encoder-

Decoder for Statistical Machine Translation,” in Proc. Conf. Empirical
Methods Natural Lang. Process. (EMNLP), Doha, Qatar, Oct. 2014,
pp. 1724–1734, doi: 10.3115/v1/D14-1179.
[6] S. | Mandal et al., “FPGA-based online | learning using approximate

hardware accelerators,” in Proc. FPL, 2021.

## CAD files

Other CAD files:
hardware/FPGA Output/probing.stp
hardware/FPGA Output/stp1.stp
